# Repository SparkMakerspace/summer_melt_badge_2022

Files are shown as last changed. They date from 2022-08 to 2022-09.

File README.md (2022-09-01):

 # Summer Melt Soldering Badge

 This badge was designed for the 2022 Summer Melt at Spark Makerspace.

 It's a *relatively* basic soldering project that results in a WiFi-enabled ice cream cone-shaped blinky pin.

## Assembly instructions:
*Coming soon...*

## Code
*Coming soon...*

## Bill of Materials (BOM)
* WeMos D1 Mini ESP8266 module (1)
* SS12D07VG4 switch (1)
* Keystone 2468 Battery Holder (1)
* DS18B20 Temperature sensor (1)
* 4.7 kOhm Resistor (THT) (1)

## Power
The badge can be powered from either two (2) AAA batteries **OR** via a USB cable connected to the ESP8266 module. Do not connect a USB cable while there are batteries in the device.

## Other
The badge also features a slot for a lanyard (not necessarily included) and a set of connector pins for [SAO](https://hackaday.io/project/175182-simple-add-ons-sao) badge add-ons often seen on Hackaday.

Interested in this kind of stuff and live in CT/RI? [Stop by our weekly Electronics & Technology Meetup on a Thursday Night!](https://electronicsnight.com).

[Spark Makerspace is a community workshop and learning center in beautiful, downtown New London, Connecticut](https://sparkmakerspace.org).

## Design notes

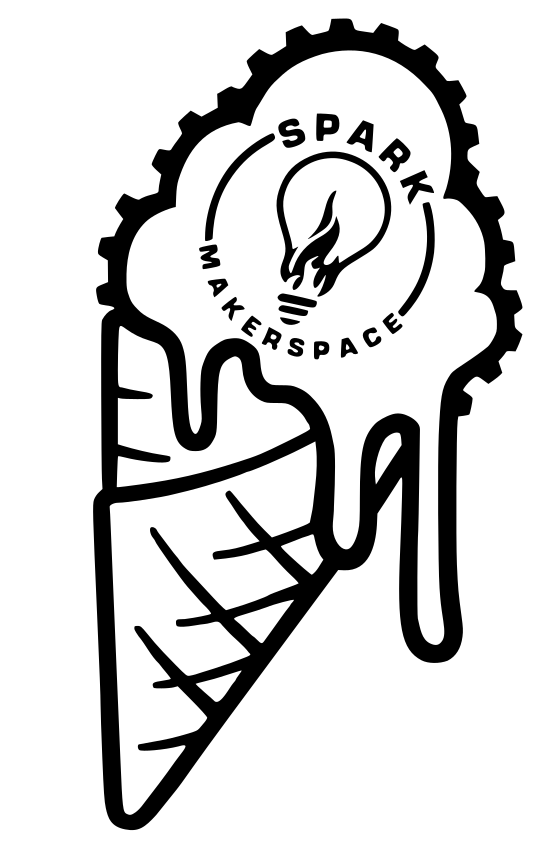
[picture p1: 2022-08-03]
artwork/melting_spark_cone.png

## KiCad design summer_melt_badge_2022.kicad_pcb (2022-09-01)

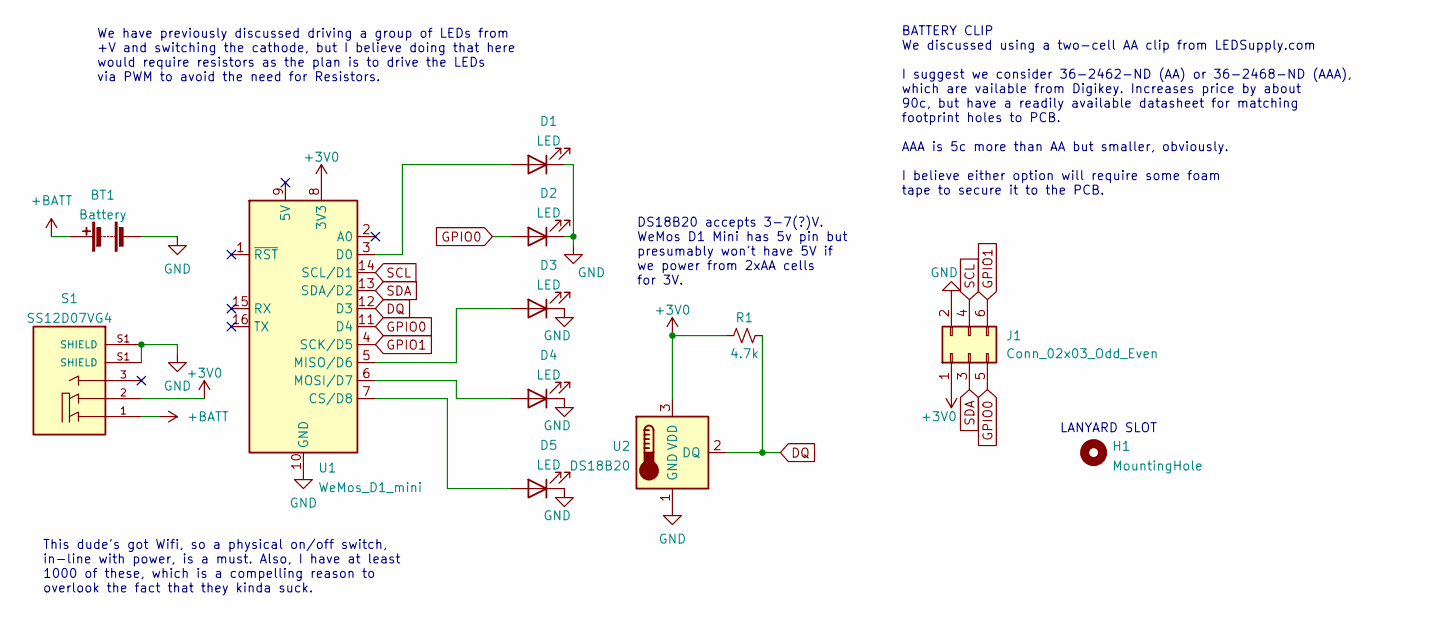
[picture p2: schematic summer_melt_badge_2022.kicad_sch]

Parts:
BT1: Battery; BatteryHolder_Keystone_2468_2xAAA
D1, D2, D3, D4, D5: LED; LED_D5.0mm
H1: MountingHole; lanyard_slot
J1: Conn_02x03_Odd_Even; PinSocket_2x03_P2.54mm_Vertical
R1: 4.7k; R_Axial_DIN0207_L6.3mm_D2.5mm_P10.16mm_Horizontal
S1: SS12D07VG4; SW_SS12D07VG4; PARTREV 1
U1: WeMos_D1_mini; WEMOS_D1_mini_light
U2: DS18B20; TO-92_Inline

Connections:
+3V0: J1.1, R1.1, S1.2, U1.8 (3V3), U2.3 (VDD)
+BATT: BT1.1 (+), S1.1
DQ: R1.2, U1.12 (D3), U2.2 (DQ)
GND: BT1.2 (-), D1.1 (K), D2.1 (K), D3.1 (K), D4.1 (K), D5.1 (K), J1.2, S1.S1 (SHIELD), U1.10 (GND), U2.1 (GND)
GPIO0: D2.2 (A), J1.5, U1.11 (D4)
GPIO1: J1.6, U1.4 (SCK/D5)
unnamed: D1.2 (A), U1.3 (D0)
unnamed: D3.2 (A), U1.5 (MISO/D6)
unnamed: D4.2 (A), U1.6 (MOSI/D7)
unnamed: D5.2 (A), U1.7 (CS/D8)
SCL: J1.4, U1.14 (SCL/D1)
SDA: J1.3, U1.13 (SDA/D2)

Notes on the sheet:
We have previously discussed driving a group of LEDs from +V and switching the cathode, but I believe doing that here would require resistors as the plan is to drive the LEDs via PWM to avoid the need for Resistors.
BATTERY CLIP We discussed using a two-cell AA clip from LEDSupply.com I suggest we consider 36-2462-ND (AA) or 36-2468-ND (AAA), which are vailable from Digikey. Increases price by about 90c, but have a readily available datasheet for matching footprint holes to PCB. AAA is 5c more than AA but smal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
LANYARD SLOT
This dude's got Wifi, so a physical on/off switch, in-line with power, is a must. Also, I have at least 1000 of these, which is a compelling reason to overlook the fact that they kinda suck.
DS18B20 accepts 3-7(?)V. WeMos D1 Mini has 5v pin but presumably won't have 5V if we power from 2xAA cells for 3V.

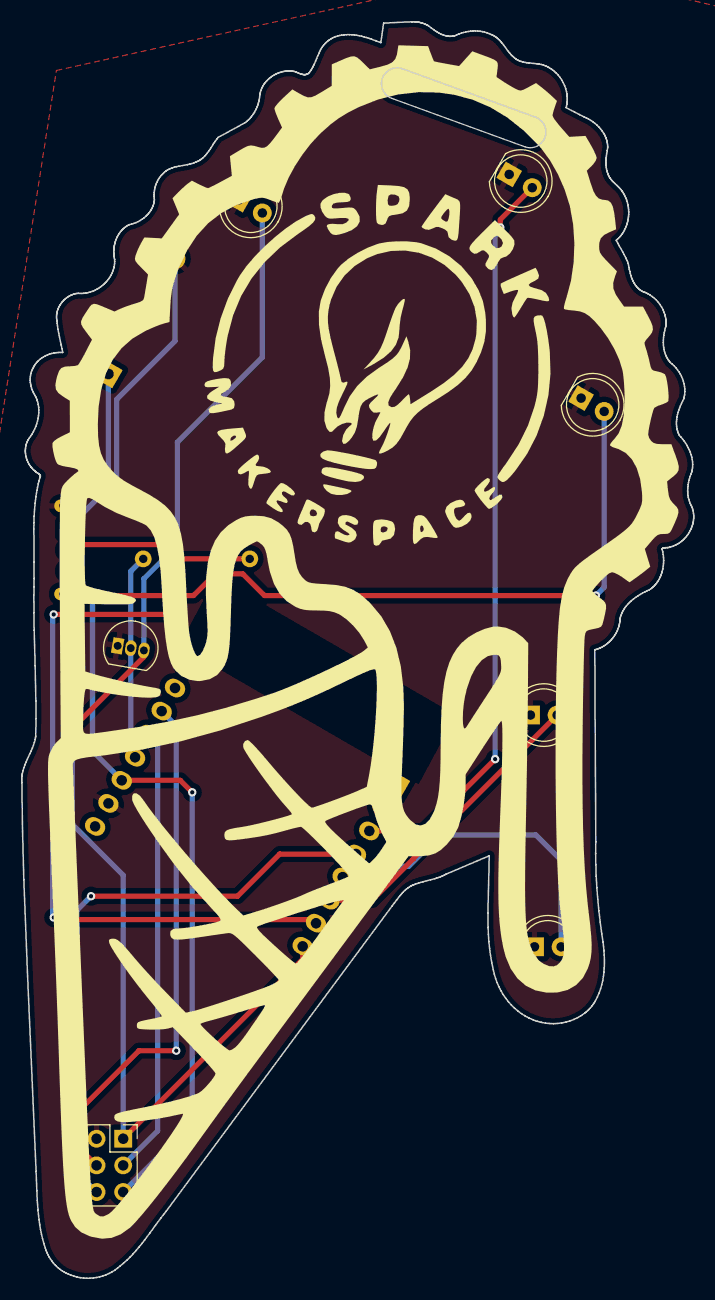
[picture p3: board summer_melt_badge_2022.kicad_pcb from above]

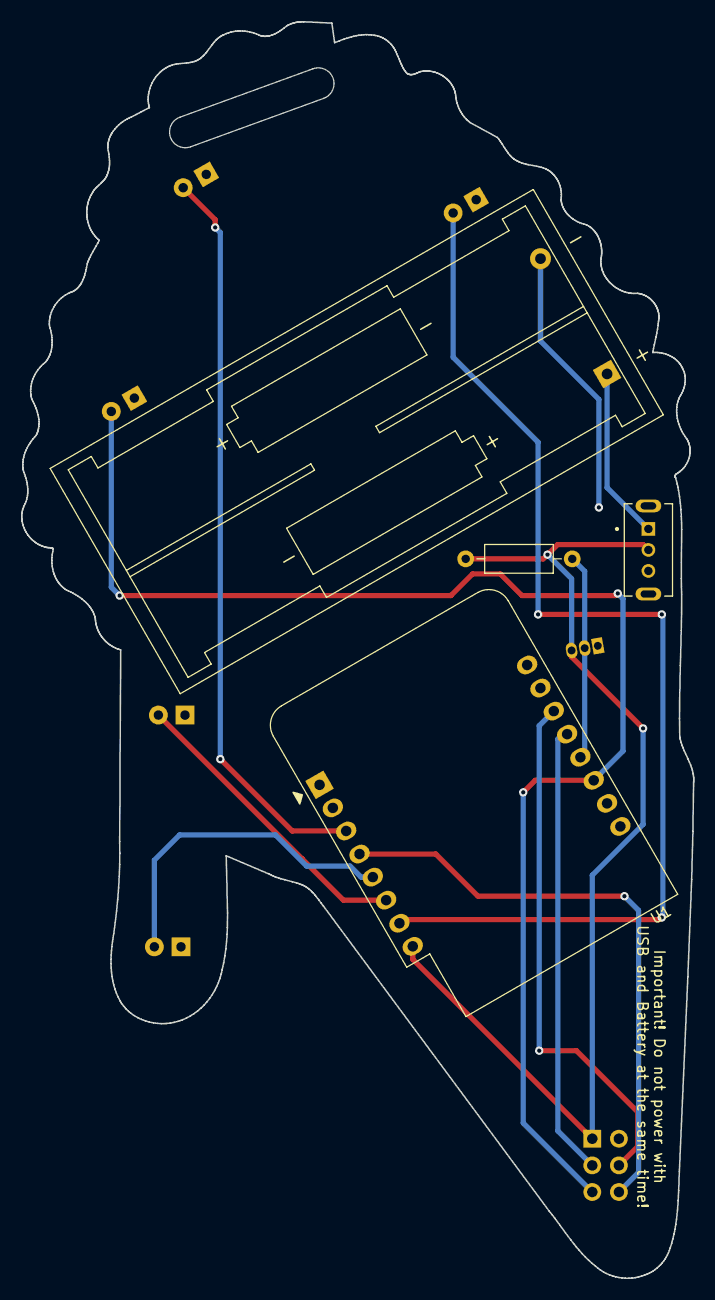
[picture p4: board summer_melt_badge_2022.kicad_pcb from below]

Board: 2 copper layers, 64.1 x 119.8 mm, 12 parts (4 on the bottom side), 12 nets.

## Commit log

2022-08-14 add graphics to kicad project
    [summer_melt_badge_2022.kicad_pcb, summer_melt_badge_2022.kicad_sch]
2022-08-16 draft schematic for review.
    [summer_melt_badge_2022.kicad_pcb, summer_melt_badge_2022.kicad_sch]
2022-08-22 I made some changes to the schematic
    [summer_melt_badge_2022.kicad_sch]
2022-08-22 footprint assignment, placement started
    [summer_melt_badge_2022.kicad_pcb, summer_melt_badge_2022.kicad_sch]
2022-08-25 draft placement complete.
    [summer_melt_badge_2022.kicad_pcb, summer_melt_badge_2022.kicad_sch]
2022-08-27 final draft placement
    [summer_melt_badge_2022.kicad_pcb, summer_melt_badge_2022.kicad_sch]
2022-08-27 Minor edits during final placement review
    [summer_melt_badge_2022.kicad_pcb, summer_melt_badge_2022.kicad_sch]
2022-08-27 draft traces
    [summer_melt_badge_2022.kicad_pcb]
2022-08-27 routed board review complete
    [summer_melt_badge_2022.kicad_pcb, summer_melt_badge_2022.kicad_sch]
2022-09-01 add readme and set up to output gerbers.
    [summer_melt_badge_2022.kicad_pcb]
2022-09-01 reorganize files
    [summer_melt_badge_2022.kicad_pcb, summer_melt_badge_2022.kicad_sch]
